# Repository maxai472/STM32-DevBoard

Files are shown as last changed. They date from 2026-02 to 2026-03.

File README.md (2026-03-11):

# STM32-DevBoard
This is my attempt to create a development board based on the STM32F103C8T6 microcontroller, with both USB-C and up to 12V input through a barrel Jack. The idea is to create this board as a learning exercise and I will expand the design into a sensor fusion board in the future.

## Features:
- SWD Programming interface
- UART interface
- I2C interface
- 2 addressable LEDs
- 6 exposed GPIO pins
- USB-C power input
- 12V barrel jack power input
- 5-12V -> 3.3V buck converter
- STM32F103C8T6 microcontroller

## Design Decision:
I went with a 12V barrel jack as I wanted to gain some experience with buck converters. In hindsight, this didn't need to be added as the USB-C is perfectly adequate for my use case.

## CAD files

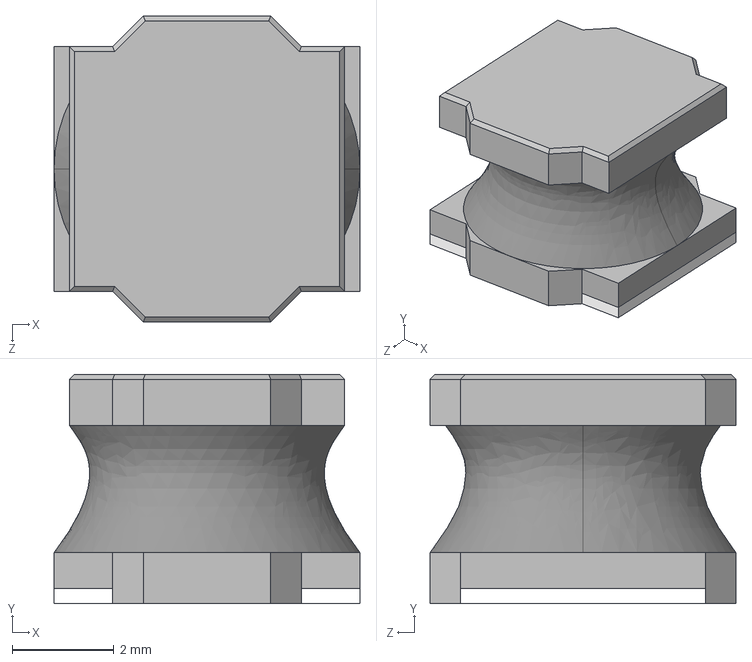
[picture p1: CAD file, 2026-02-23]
Resources/3D Models/SRN6045TA-2R2Y.step
6.00 x 4.50 x 6.00 mm

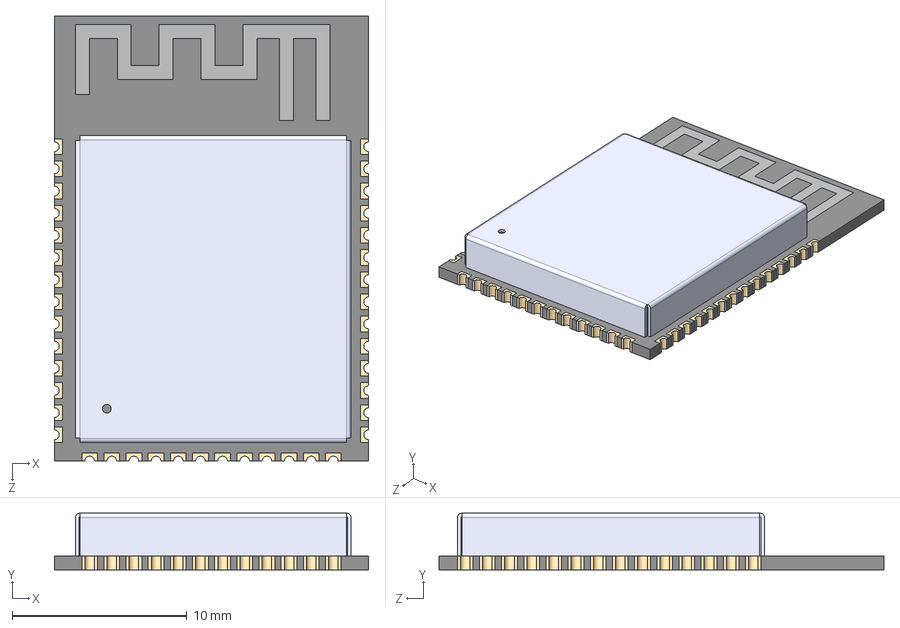
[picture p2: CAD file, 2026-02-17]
Resources/3D Models/ESP32-S3-WROOM-1-N8R8.step
18.0 x 3.25 x 25.5 mm

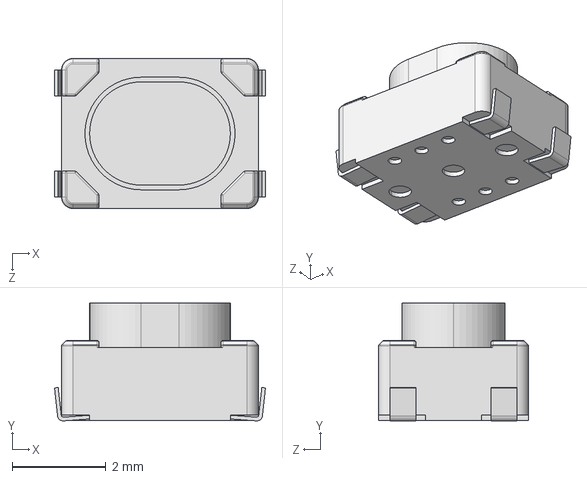
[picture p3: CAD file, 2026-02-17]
Resources/3D Models/TL3365AF180QG.step
4.50 x 2.51 x 3.20 mm

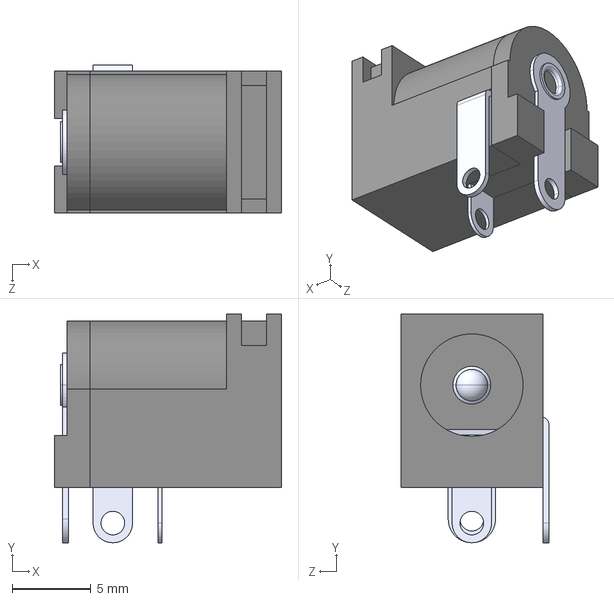
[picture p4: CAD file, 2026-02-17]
Resources/3D Models/PJ-002A.step
14.4 x 14.5 x 9.40 mm

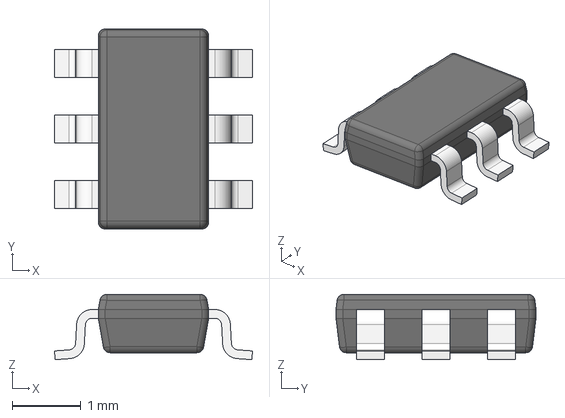
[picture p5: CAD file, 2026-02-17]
Resources/3D Models/DDC0006A.stp
2.87 x 2.90 x 0.947 mm
BODY-SOT
LEAD-SOT x 6

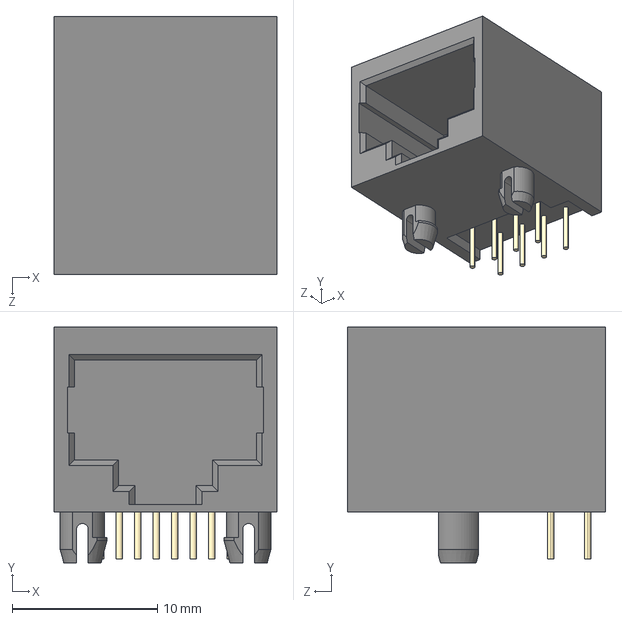
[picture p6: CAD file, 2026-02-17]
Resources/3D Models/54602-908LF.STEP
15.3 x 16.2 x 17.7 mm

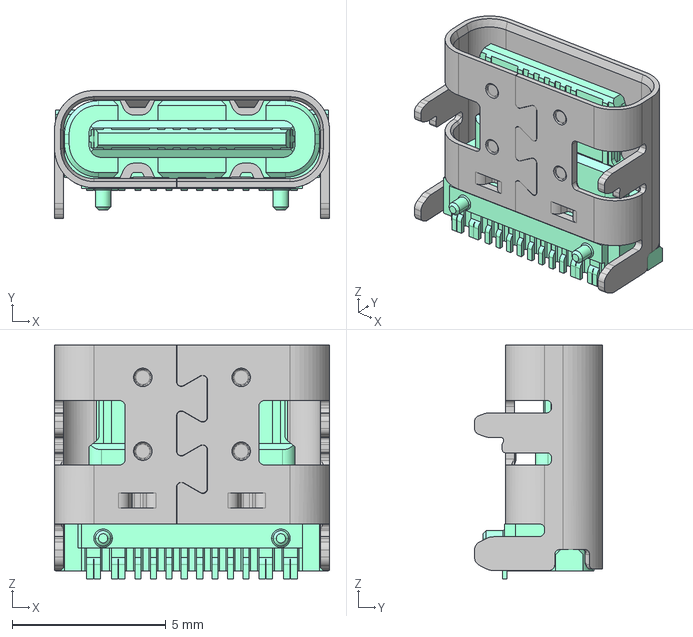
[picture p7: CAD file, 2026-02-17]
Resources/3D Models/12402012E212A.step
8.94 x 4.16 x 7.60 mm

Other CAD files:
Resources/3D Models/VLS6045EX-2R2N.step

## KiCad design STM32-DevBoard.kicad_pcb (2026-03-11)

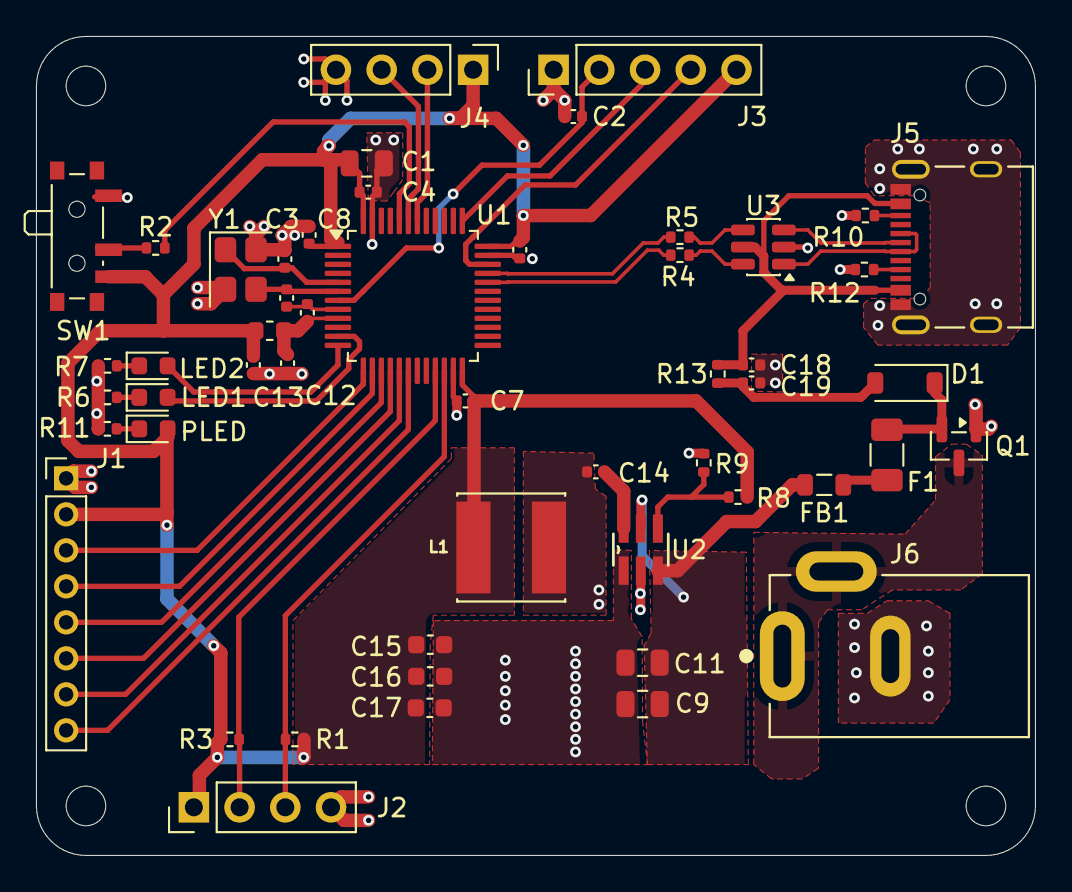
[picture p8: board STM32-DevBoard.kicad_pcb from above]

Board: 2 copper layers, 55.5 x 45.5 mm, 56 parts (0 on the bottom side), 42 nets.

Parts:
C1, C9, C11: 10u; C_0805_2012Metric
C2, C4, C6, C7, C8, C10, C14: 100n; C_0402_1005Metric
C3, C5: 10p; C_0402_1005Metric
C12, C13: 1u; C_0402_1005Metric
C15, C16, C17: 22uF; C_0603_1608Metric
C18, C19: 470n; C_0402_1005Metric
D1: B5819W; D_SOD-123
F1: 250mA; Fuse_1206_3216Metric
FB1: 600 @ 600MHz; L_0805_2012Metric
FB2: 120R; L_0603_1608Metric
H1, H2, H3, H4: MountingHole; MountingHole_2.2mm_M2
J1: Conn_01x08_Pin; PinHeader_1x08_P2.00mm_Vertical
J2: I2C Bus 1; PinHeader_1x04_P2.54mm_Vertical
J3: Serial Debugger; PinHeader_1x05_P2.54mm_Vertical
J4: USART1; PinHeader_1x04_P2.54mm_Vertical
J5: 12402012E212A; AMPHENOL_12402012E212A
J6: PJ-002A; CUI_PJ-002A
L1: 2.2u; IND_VLS6045EX-2R2N
LED1: LED1; LED_0603_1608Metric
LED2: LED2; LED_0603_1608Metric
PLED: PLED; LED_0603_1608Metric
Q1: AO3401A; SOT-23
R1, R3: 4.7K; R_0402_1005Metric
R2, R9: 10k; R_0402_1005Metric
R4, R5: 22R; R_0402_1005Metric
R6, R7, R11: 1K; R_0402_1005Metric
R8: 33k2; R_0402_1005Metric
R10, R12: 5k1; R_0402_1005Metric
R13: R; R_0402_1005Metric
SW1: SW_SPDT; SW_SPDT_PCM12
U1: STM32F103C8T6; LQFP-48_7x7mm_P0.5mm
U2: TPS563209DDCR; DDC0006A
U3: USBLC6-2SC6; SOT-23-6
Y1: 16MHz; Crystal_SMD_3225-4Pin_3.2x2.5mm

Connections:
+3.3V: C1.1, C4.1, C6.1, C7.1, C8.1, C13.1, C15.1, C16.1, C17.1, FB2.2, J1.2, J2.1, J3.5, J4.1, L1.2, PLED.2 (A), R1.2, R3.2, R8.1, SW1.3 (C), U1.1 (VBAT), U1.24 (VDD), U1.36 (VDD), U1.48 (VDD)
+3.3VA: C10.1, C12.1, FB2.1, U1.9 (VDDA)
+12V: J6.1, J6.3, Q1.3 (D)
/+VIN_FILTERED: C9.1, C11.1, FB1.2, U2.3 (VIN), U2.5 (EN)
/+VIN_FUSED: F1.2, FB1.1
/+VIN_PROTECTED: D1.1 (K), F1.1, Q1.2 (S)
/BOOT0: R2.2, U1.44 (BOOT0)
/CC1_A: J5.A5 (CC1_A), R12.1
/CC1_B: J5.B5 (CC1_B), R10.1
/HSE_IN: C3.1, U1.5 (PD0), Y1.1
/HSE_OUT: C5.1, U1.6 (PD1), Y1.3
/LED1+: LED1.2 (A), U1.11 (PA1)
/LED1-: LED1.1 (K), R6.1
/LED2+: LED2.2 (A), U1.12 (PA2)
/LED2-: LED2.1 (K), R7.1
/PLED_OUT: PLED.1 (K), R11.2
/SW_BOOT0: R2.1, SW1.2 (B)
/SW_OUT: C14.1, L1.1, U2.2 (SW)
/USBC_D+: J5.A6 (D+_A), J5.B6 (D+_B), U3.1 (I/O1)
/USBC_D-: J5.A7 (D-_A), J5.B7 (D-_B), U3.3 (I/O2)
/VBST_OUT: C14.2, U2.6 (VBST)
/VFB_OUT: R8.2, R9.1, U2.4 (VFB)
GND: C1.2, C2.2, C3.2, C4.2, C5.2, C6.2, C7.2, C8.2, C9.2, C10.2, C11.2, C12.2, C13.2, C15.2, C16.2, C17.2, C18.2, C19.2, J1.1, J2.4, J3.1, J4.4, J5.A1_B12 (GND), J5.B1_A12 (GND__1), J5.SH1 (SHIELD), J5.SH2 (SHIELD__1), J5.SH3 (SHIELD__2), J5.SH4 (SHIELD__3), J6.2, Q1.1 (G), R6.2, R7.2, R9.2, R10.2, R11.1, R12.2, SW1.1 (A), U1.8 (VSSA), U1.23 (VSS), U1.35 (VSS), U1.47 (VSS), U2.1 (GND), U3.2 (GND), Y1.2, Y1.4
GPIO1: J1.3, U1.13 (PA3)
GPIO2: J1.4, U1.14 (PA4)
GPIO3: J1.5, U1.15 (PA5)
GPIO4: J1.6, U1.16 (PA6)
GPIO5: J1.7, U1.17 (PA7)
GPIO6: J1.8, U1.18 (PB0)
I2C1_SCL: J2.3, R1.1, U1.22 (PB11)
I2C1_SDA: J2.2, R3.1, U1.21 (PB10)
NRST: C2.1, J3.2, U1.7 (NRST)
unnamed: R4.1, U1.32 (PA11)
unnamed: R5.1, U1.33 (PA12)
SWCLK: J3.3, U1.37 (PA14)
SWDIO: J3.4, U1.34 (PA13)
USART1_RX: J4.3, U1.43 (PB7)
USART1_TX: J4.2, U1.42 (PB6)
USB_D+: R5.2, U3.4 (I/O2)
USB_D-: R4.2, U3.6 (I/O1)
VBUS: C18.1, J5.A4_B9 (VBUS), J5.B4_A9 (VBUS__1), R13.1, U3.5 (VBUS)
VBUSF: C19.1, D1.2 (A), R13.2

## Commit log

2026-02-17 Schematic complete, preliminary pcb layout done
    [12402012E212A.step, 54602-908LF.STEP, DDC0006A.stp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]
2026-02-18 Board constraints, layout, and initial traces done
    [STM32-DevBoard.kicad_pcb, STM32-DevBoard.kicad_sch]
2026-02-18 extra gpio
    [STM32-DevBoard.kicad_sch]
2026-02-20 part descs
    [STM32-DevBoard.kicad_sch]
2026-02-21 Added component information
    [STM32-DevBoard.kicad_sch]
2026-02-22 Added a bit more component information
    [STM32-DevBoard.kicad_sch]
2026-02-23 Added footprints and models, progressed PCB layout. TODO: rename nets
    [SRN6045TA-2R2Y.step, STM32-DevBoard.kicad_pcb, STM32-DevBoard.kicad_sch]
2026-03-09 Completed net names
    [STM32-DevBoard.kicad_pcb, STM32-DevBoard.kicad_sch]
2026-03-10 Routing progressed
    [STM32-DevBoard.kicad_pcb, STM32-DevBoard.kicad_sch]
2026-03-11 Routing Complete, need to finish off net labels
    [SRN6045TA-2R2Y.step, STM32-DevBoard.kicad_pcb]
2026-03-11 Net labels partially complete, still more to go
    [STM32-DevBoard.kicad_sch]
